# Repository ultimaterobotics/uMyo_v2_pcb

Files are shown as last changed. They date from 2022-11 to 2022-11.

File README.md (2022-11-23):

# PCB for uMyo (v2)

This is a KiCAD 6 project for the first produced batch of uMyo devices. There are some things worth improving, but overall it works as intended.

PCB is licensed under CERN-OHL-P-2.0 - we use MIT license for our software/firmware projects, but it seems that for hardware it doesn't work well, so we applied this option. In our understanding, it should permit anyone to use this design as a whole or incorporate its parts into other projects with no restrictions (including commercial use), except for claiming that it was not derived from our project. If you want to use it but something in this license prevents you from doing that - please contact us, we'll see what can be done about it.

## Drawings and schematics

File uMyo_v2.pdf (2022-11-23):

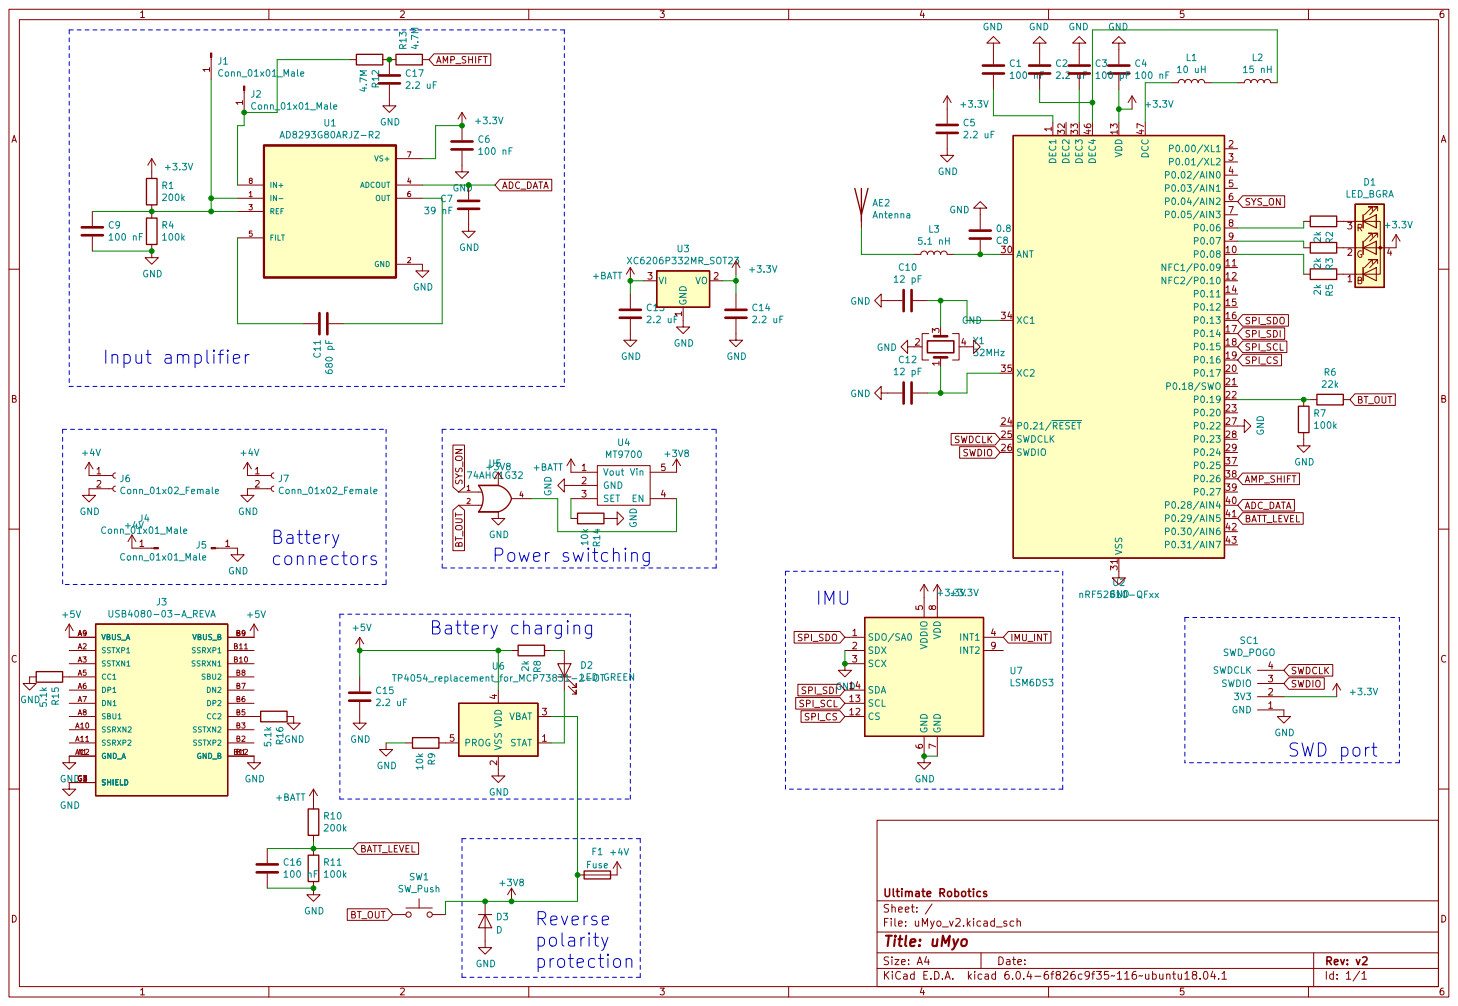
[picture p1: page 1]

1 P0.08 10 NFC1/P0.09 11 NFC2/P0.10 12 VDD 13 P0.11 14 P0.12 15 P0.13 16 P0.14 17 P0.15 18 P0.16 19 P0.00/XL1 2 P0.17 20 P0.18/SWO 21 P0.19 22 P0.20 23 P0.21/~{RESET} 24 SWDCLK 25 SWDIO 26 P0.22 27 P0.23 28 P0.24 29 P0.01/XL2 3 ANT 30 VSS 31 DEC2 32 DEC3 33 XC1 34 XC2 35 P0.25 37 P0.26 38 P0.27 39 P0.02/AIN0 4 P0.28/AIN4 40 P0.29/AIN5 41 P0.30/AIN6 42 P0.31/AIN7 43 DEC4 46 DCC 47 P0.03/AIN1 5 P0.04/AIN2 6 P0.05/AIN3 7 P0.06 8 P0.07 9 U2

File: uMyo_v2.kicad_sch Sheet: / Ultimate Robotics

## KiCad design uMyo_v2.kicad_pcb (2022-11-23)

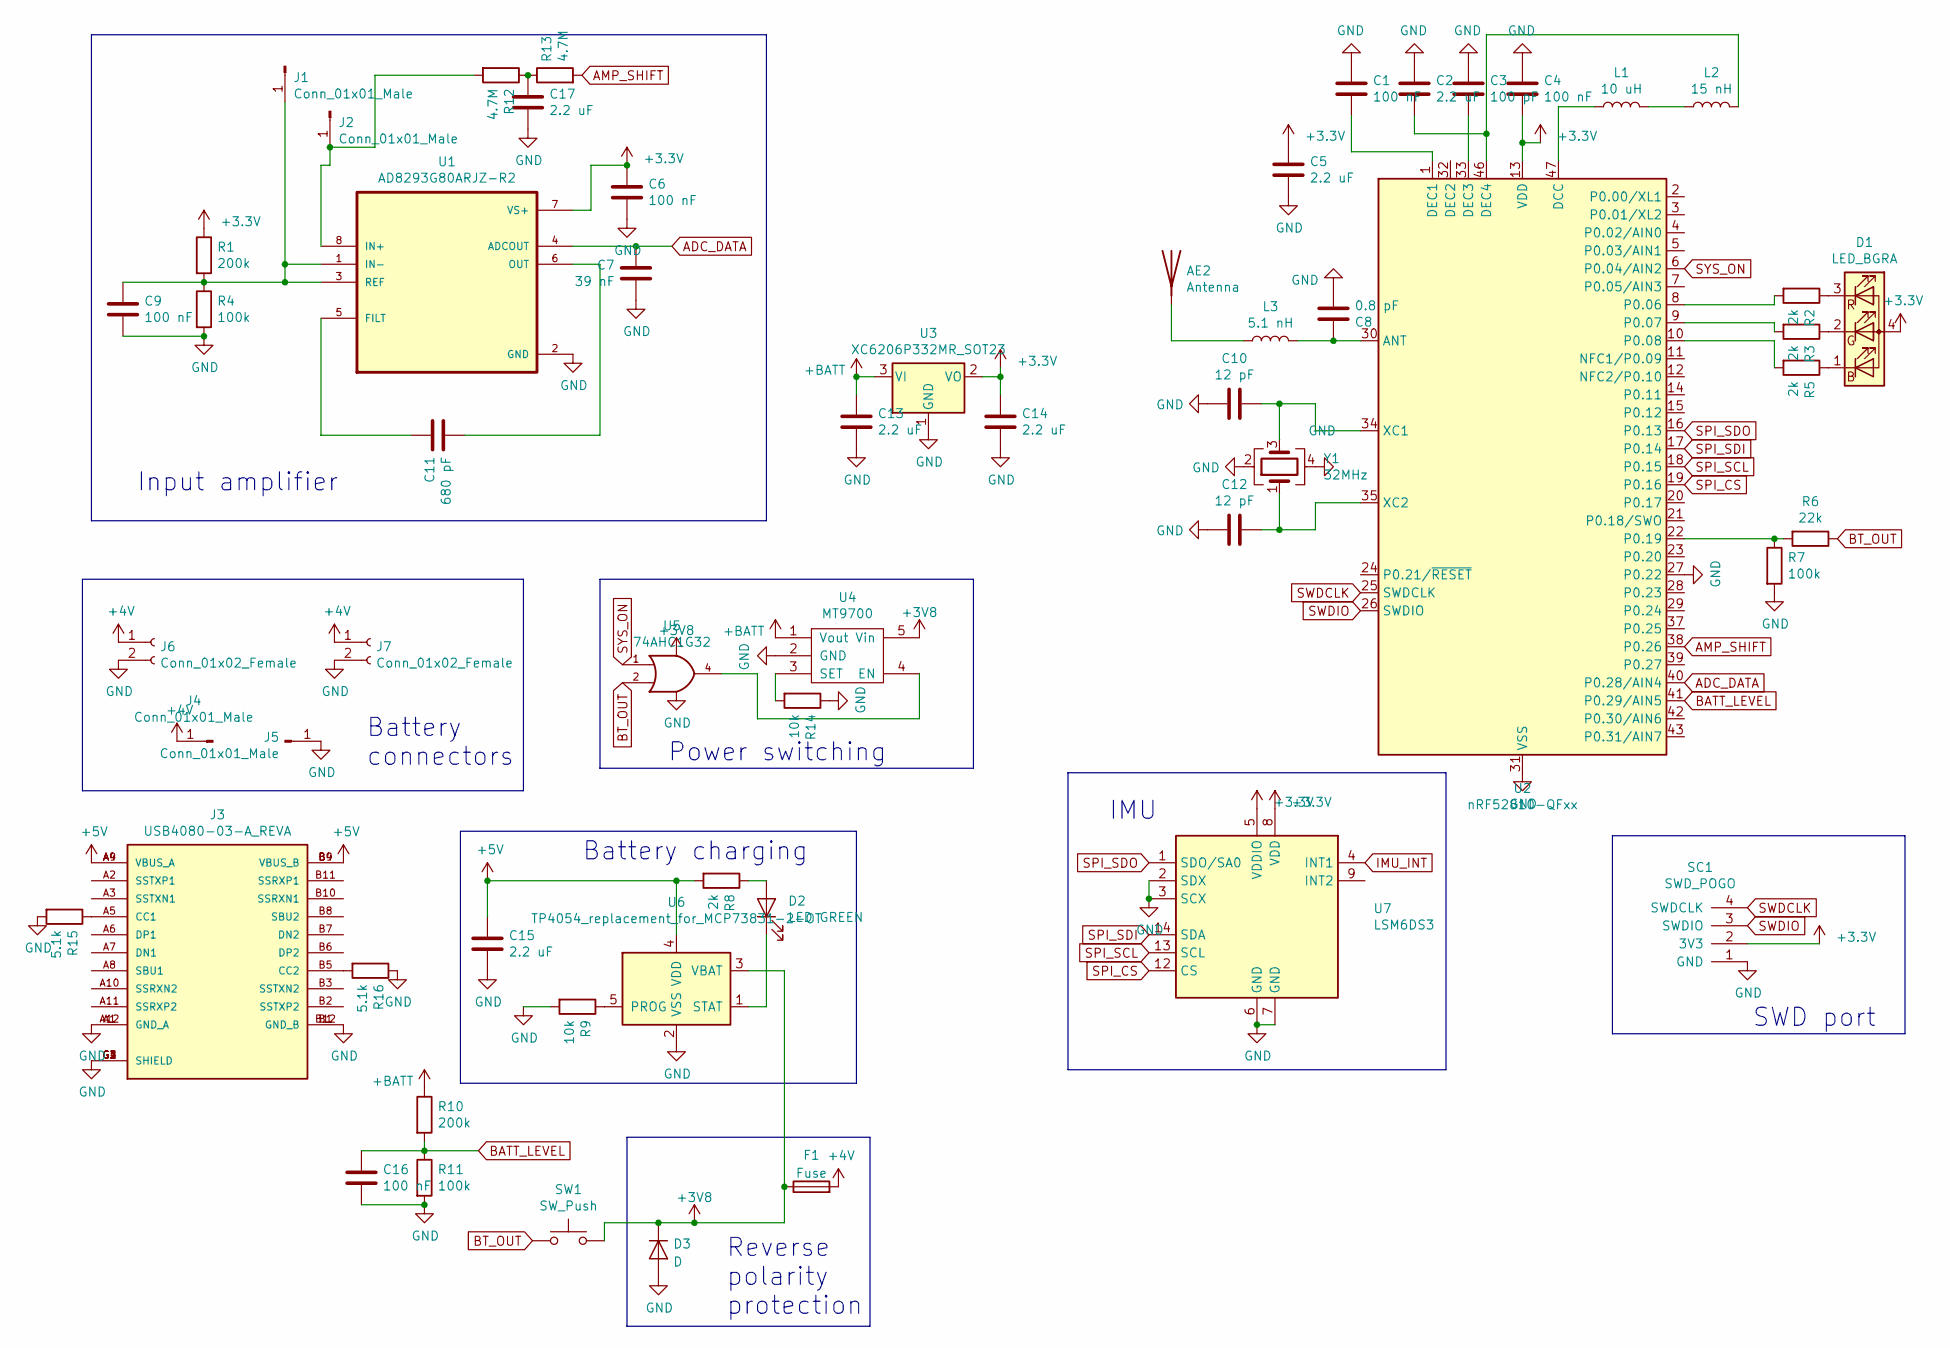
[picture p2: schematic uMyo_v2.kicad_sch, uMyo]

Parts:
AE2: Antenna; XCVR_YC0010AA; JLCPN C504003
C1, C4, C6, C9, C16: 100 nF; C_0402_1005Metric; JLCPN C1525
C2, C5, C13, C14, C15, C17: 2.2 uF; C_0402_1005Metric; JLCPN C12530
C3: 100 pF; C_0402_1005Metric; JLCPN C1546
C7: 39 nF; C_0402_1005Metric; JLCPN C117753
C8: 0.8 pF; C_0402_1005Metric; JLCPN C88902
C10, C12: 12 pF; C_0402_1005Metric; JLCPN C1547
C11: 680 pF; C_0402_1005Metric; JLCPN C113781
D1: LED_BGRA; LED_RGB_0603_a4; JLCPN C282128
D2: LED GREEN; LED_0603_1608Metric; JLCPN C72043
D3: D; D_SOD-323; JLCPN C191023
F1: Fuse; Fuse_0603_1608Metric; JLCPN C207011
J1, J2: Conn_01x01_Male; textile_button_6mm
J3: USB4080-03-A_REVA; PARTREV A; JLCPN C183607
J4, J5: Conn_01x01_Male; conn_06_20
J6, J7: Conn_01x02_Female; JST_PH_S2B-PH-K_1x02_P2.00mm_Horizontal; JLCPN C173752
L1: 10 uH; L_0603_1608Metric; JLCPN C1035
L2: 15 nH; L_0402_1005Metric; JLCPN C27143
L3: 5.1 nH; L_0402_1005Metric; JLCPN C86066
R1, R10: 200k; R_0402_1005Metric; JLCPN C25764
R2, R3, R5, R8: 2k; R_0402_1005Metric; JLCPN C4109
R4, R7, R11: 100k; R_0402_1005Metric; JLCPN C25741
R6: 22k; R_0402_1005Metric; JLCPN C25768
R9, R14: 10k; R_0402_1005Metric; JLCPN C25744
R12, R13: 4.7M; R_0402_1005Metric; JLCPN C227116
R15, R16: 5.1k; R_0402_1005Metric; JLCPN C25905
SC1: SWD_POGO
SW1: SW_Push; SW_SPST_CK_RS282G05A3; JLCPN C2845294
U1: AD8293G80ARJZ-R2; SOT-23-8; JLCPN C141950
U2: nRF52810-QFxx; QFN-48-1EP_6x6mm_Pitch0.4mm; JLCPN C141828
U3: XC6206P332MR_SOT23; SOT-23; JLCPN C5446
U4: MT9700; SOT-23-5; JLCPN C89855
U5: 74AHC1G32; SOT-23-5; JLCPN C507209
U6: TP4054_replacement_for_MCP73831-2-OT; SOT-23-5; JLCPN C668215
U7: LSM6DS3; LGA-14_3x2.5mm_P0.5mm_LayoutBorder3x4y; JLCPN C967633
Y1: 32MHz; Crystal_SMD_2016-4Pin_2.0x1.6mm; JLCPN C843260

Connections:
+3V3: C4.1, C5.2, C6.2, C14.2, D1.4 (A), R1.1, SC1.2 (3V3), U1.7 (VS+), U2.13 (VDD), U2.36 (VDD), U2.48 (VDD), U3.2 (VO), U7.5 (VDDIO), U7.8 (VDD)
+3V8: D3.1 (K), F1.1, SW1.2, U4.5 (Vin), U5.5 (VCC), U6.3 (VBAT)
+4V: F1.2, J4.1, J6.1, J7.1
+5V: C15.2, J3.A4 (VBUS_A), J3.A9 (VBUS_A), J3.B4 (VBUS_B), J3.B9 (VBUS_B), R8.2, U6.4 (VDD)
+BATT: C13.2, R10.1, U3.3 (VI), U4.1 (Vout)
ADC_DATA: C7.1, U1.4 (ADCOUT), U2.40 (P0.28/AIN4)
AMP_SHIFT: R13.2, U2.38 (P0.26)
BATT_LEVEL: C16.2, R10.2, R11.1, U2.41 (P0.29/AIN5)
BT_OUT: R6.1, SW1.1, U5.2
GND: C1.2, C2.2, C3.2, C4.2, C5.1, C6.1, C7.2, C8.2, C9.1, C10.1, C12.1, C13.1, C14.1, C15.1, C16.1, C17.1, D3.2 (A), J3.A1 (GND_A), J3.A12 (GND_A), J3.B1 (GND_B), J3.B12 (GND_B), J3.G1 (SHIELD), J3.G2 (SHIELD), J3.G3 (SHIELD), J3.G4 (SHIELD), J5.1, J6.2, J7.2, R4.2, R7.2, R9.2, R11.2, R14.1, R15.2, R16.1, SC1.1 (GND), U1.2 (GND), U2.27 (P0.22), U2.31 (VSS), U2.45 (VSS), U2.49 (VSS), U3.1 (GND), U4.2 (GND), U5.3 (GND), U6.2 (VSS), U7.2 (SDX), U7.3 (SCX), U7.6 (GND), U7.7 (GND), Y1.2, Y1.4
IMU_INT: U7.4 (INT1)
unnamed: AE2.1 (A), L3.1
unnamed: C1.1, U2.1 (DEC1)
unnamed: C2.1, L2.2, U2.46 (DEC4)
unnamed: C3.1, U2.33 (DEC3)
unnamed: C8.1, L3.2, U2.30 (ANT)
unnamed: C9.2, J1.1, R1.2, R4.1, U1.1 (IN-), U1.3 (REF)
unnamed: C10.2, U2.34 (XC1), Y1.3
unnamed: C11.1, U1.5 (FILT)
unnamed: C11.2, U1.6 (OUT)
unnamed: C12.2, U2.35 (XC2), Y1.1
unnamed: C17.2, R12.1, R13.1
unnamed: D1.1 (BK), R5.1
unnamed: D1.2 (GK), R3.1
unnamed: D1.3 (RK), R2.1
unnamed: D2.1 (K), U6.1 (STAT)
unnamed: D2.2 (A), R8.1
unnamed: J2.1, R12.2, U1.8 (IN+)
unnamed: J3.A5 (CC1), R15.1
unnamed: J3.B5 (CC2), R16.2
unnamed: L1.1, U2.47 (DCC)
unnamed: L1.2, L2.1
unnamed: R2.2, U2.8 (P0.06)
unnamed: R3.2, U2.9 (P0.07)
unnamed: R5.2, U2.10 (P0.08)
unnamed: R6.2, R7.1, U2.22 (P0.19)
unnamed: R9.1, U6.5 (PROG)
unnamed: R14.2, U4.3 (SET)
unnamed: U4.4 (EN), U5.4
SPI_CS: U2.19 (P0.16), U7.12 (CS)
SPI_SCL: U2.18 (P0.15), U7.13 (SCL)
SPI_SDI: U2.17 (P0.14), U7.14 (SDA)
SPI_SDO: U2.16 (P0.13), U7.1 (SDO/SA0)
SWDCLK: SC1.4 (SWDCLK), U2.25 (SWDCLK)
SWDIO: SC1.3 (SWDIO), U2.26 (SWDIO)
SYS_ON: U2.6 (P0.04/AIN2), U5.1

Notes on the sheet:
SWD port
Power switching
Battery connectors
Battery charging
IMU
Reverse polarity protection
Input amplifier

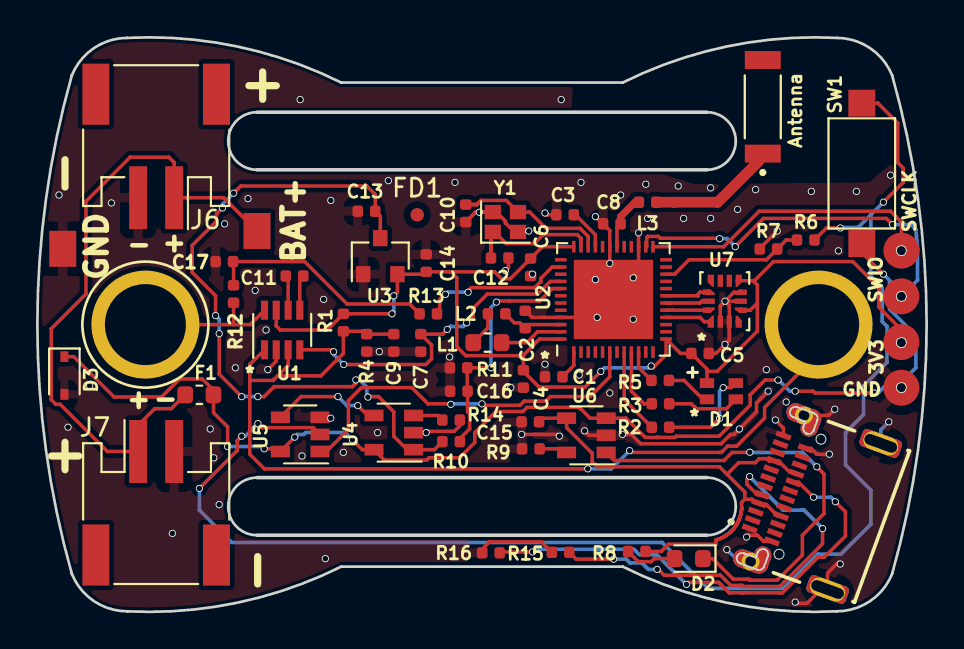
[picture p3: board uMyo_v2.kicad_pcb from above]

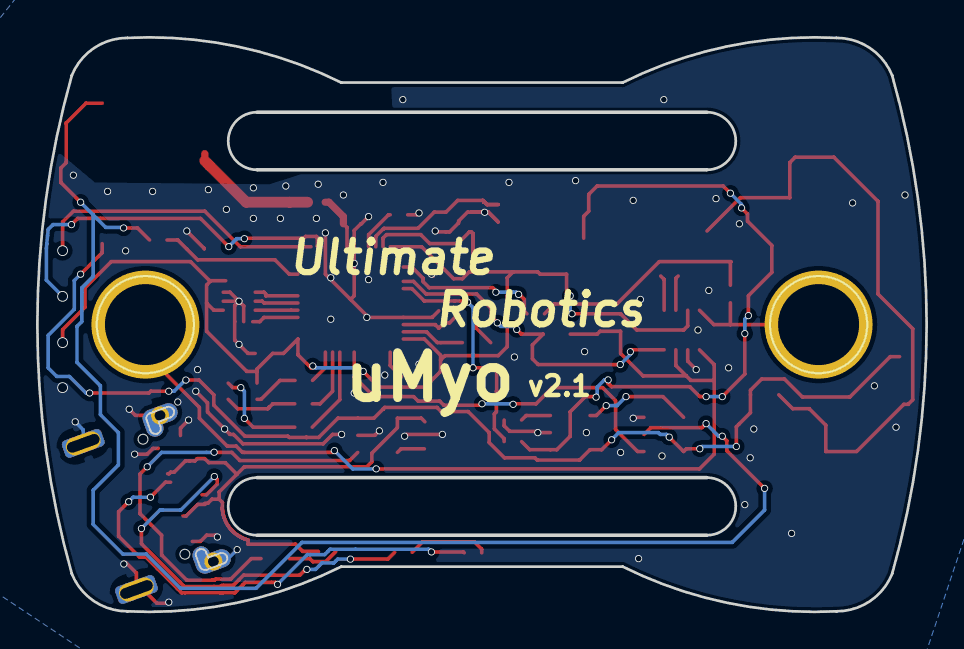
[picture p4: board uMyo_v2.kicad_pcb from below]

Board: 2 copper layers, 49.4 x 31.9 mm, 59 parts (2 on the bottom side), 45 nets.

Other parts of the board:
FD1: Fiducial_0.75mm_Dia_1.5mm_Outer
